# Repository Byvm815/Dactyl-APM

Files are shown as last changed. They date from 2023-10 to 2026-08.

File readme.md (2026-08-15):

## Note：I am not good at english, so writted in chinese

## 注：淘宝店铺：无名科技Nologo，有[RP2040_pico_Mini](https://item.taobao.com/item.htm?id=722773242430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)的开发板，板子宽度和ProMicro一致，无需修改外壳接口宽度,完美替换32U4。但本项目的支架适配更广，可使用常见的STM32F103、RP2040的开发板
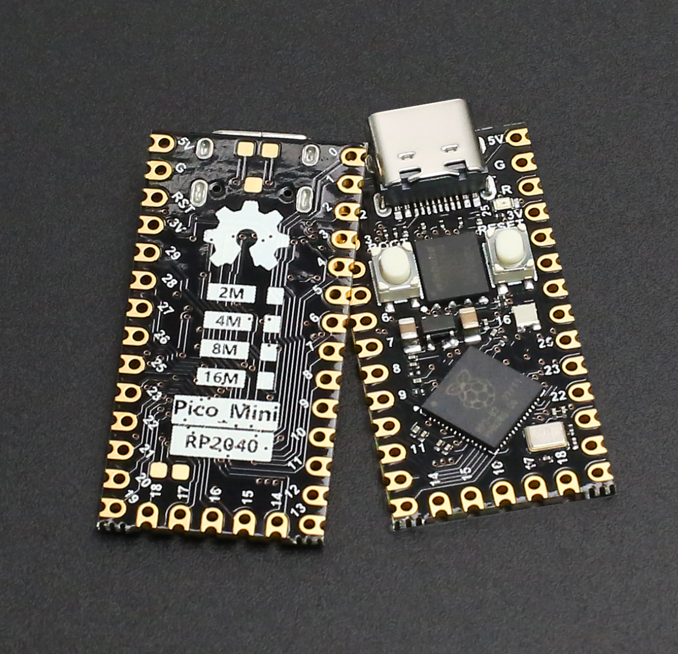
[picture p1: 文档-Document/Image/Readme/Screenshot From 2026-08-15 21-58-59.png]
Pico_Mini RP2040（16M）


## 注：本项目外壳接口宽度拓宽，与原支架不适配
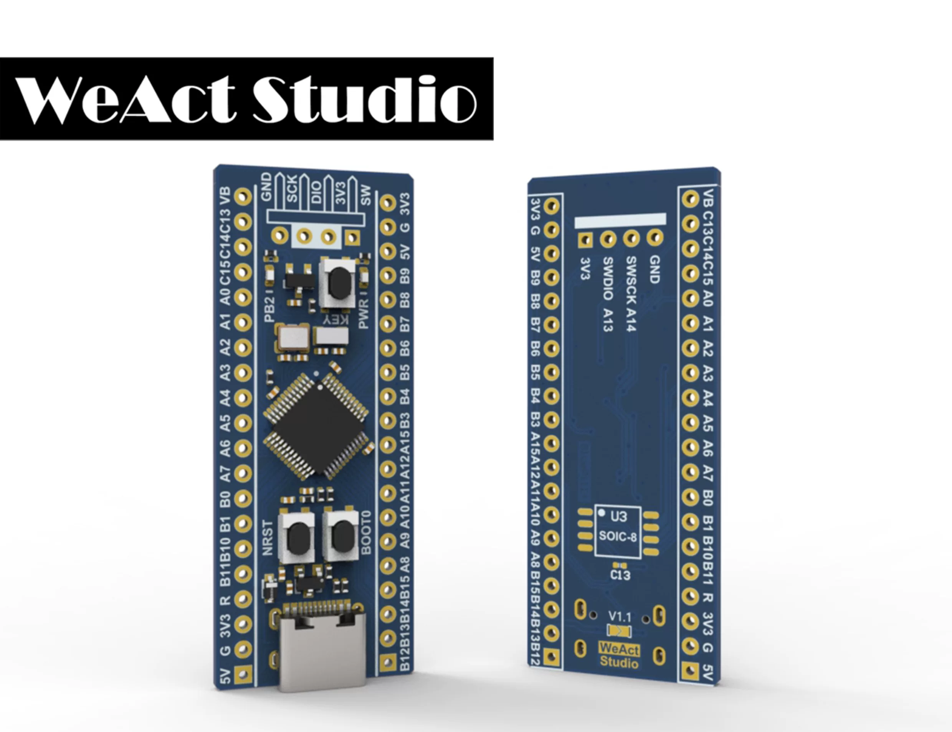
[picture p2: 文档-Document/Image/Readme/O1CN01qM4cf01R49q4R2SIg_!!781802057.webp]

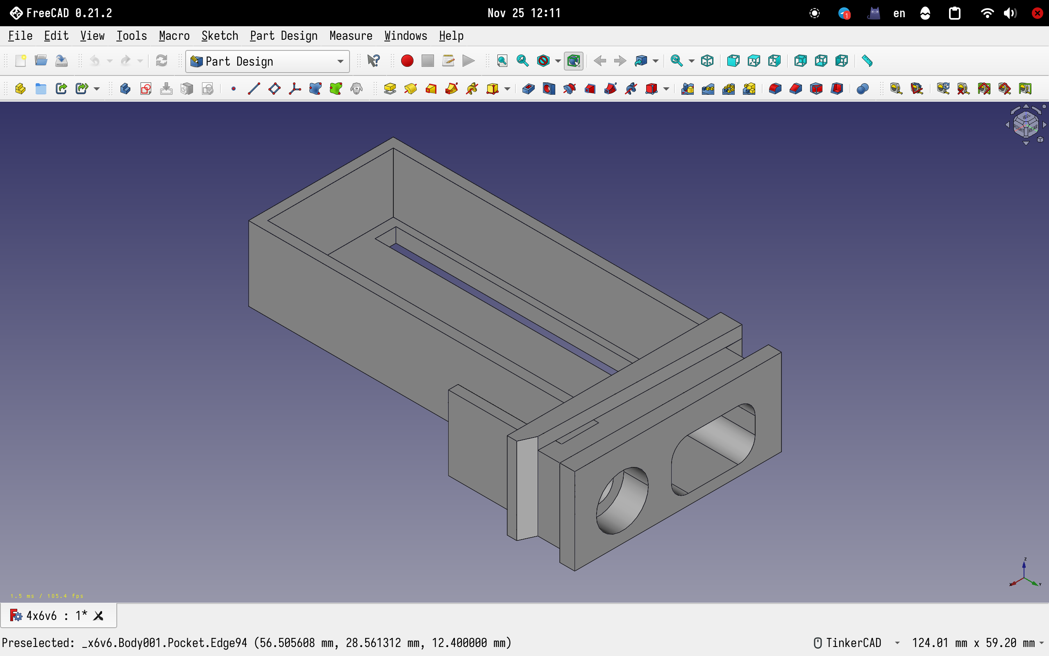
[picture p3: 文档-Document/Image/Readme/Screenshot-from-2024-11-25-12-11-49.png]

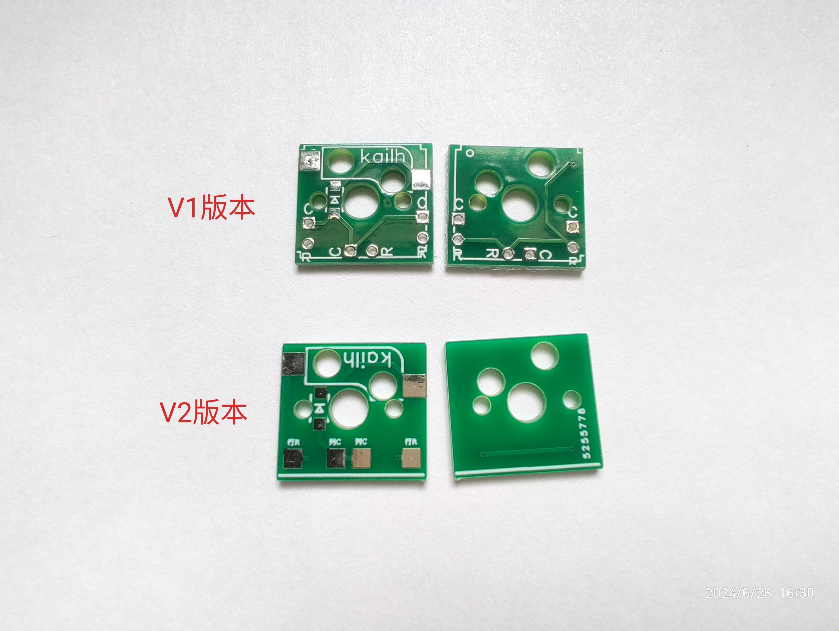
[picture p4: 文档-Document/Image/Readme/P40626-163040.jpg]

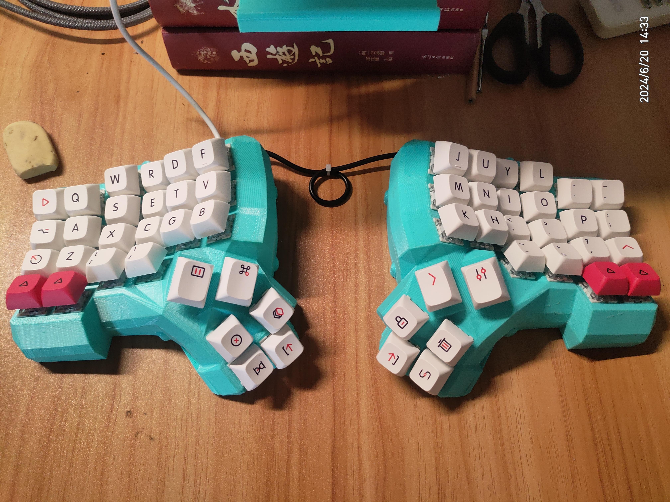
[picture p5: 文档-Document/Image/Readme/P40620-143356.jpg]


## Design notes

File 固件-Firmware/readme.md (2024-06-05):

This project test in vial-qmk version: ee7f5acefb3fa3e69b1dd2ef325ede1698bef1c9

***STM32F103xB_uf2boot.ld*** file copy from https://github.com/qmk/qmk_firmware/tree/master/platforms/chibios/boards/common/ld

Copy ***4x6v6/固件-Firmware/dactyl_apm*** to ***vial-qmk/keyboards***

Build in qmk:
```
qmk setup -H ~/Git/vial-qmk

qmk flash -kb dactyl_apm/4x6v6 -km vial -bl uf2-split-right

qmk flash -kb dactyl_apm/4x6v6 -km vial -bl uf2-split-left
```

Or build in make(pkgs:gnumake,python3,gcc-arm-embedded-8):
```
make dactyl_apm/4x6v6:vial:uf2-split-right

make dactyl_apm/4x6v6:vial:uf2-split-left
```

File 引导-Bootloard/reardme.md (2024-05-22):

Use openOCD to flash ***4x6v6/引导-Bootloard/uf2boot.bin*** , basic addr is 0x08000000

I'm using DAP-Link.

The way of link:

*DAP-Link*  ->  *APM32 Board*
TCK/CK      ->  SCK

GND         ->  GND

TMD/IO      ->  DIO

3V3         ->  3V3

Flash command
'''
sudo openocd -f interface/cmsis-dap.cfg -f target/stm32f1x.cfg -c "init;halt;reset halt;flash write_image erase uf2boot.bin 0x08000000;shutdown;"
'''

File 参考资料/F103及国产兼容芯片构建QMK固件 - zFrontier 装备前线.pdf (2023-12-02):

# F103及国产兼容芯⽚构建QMK固件

## 机械键盘

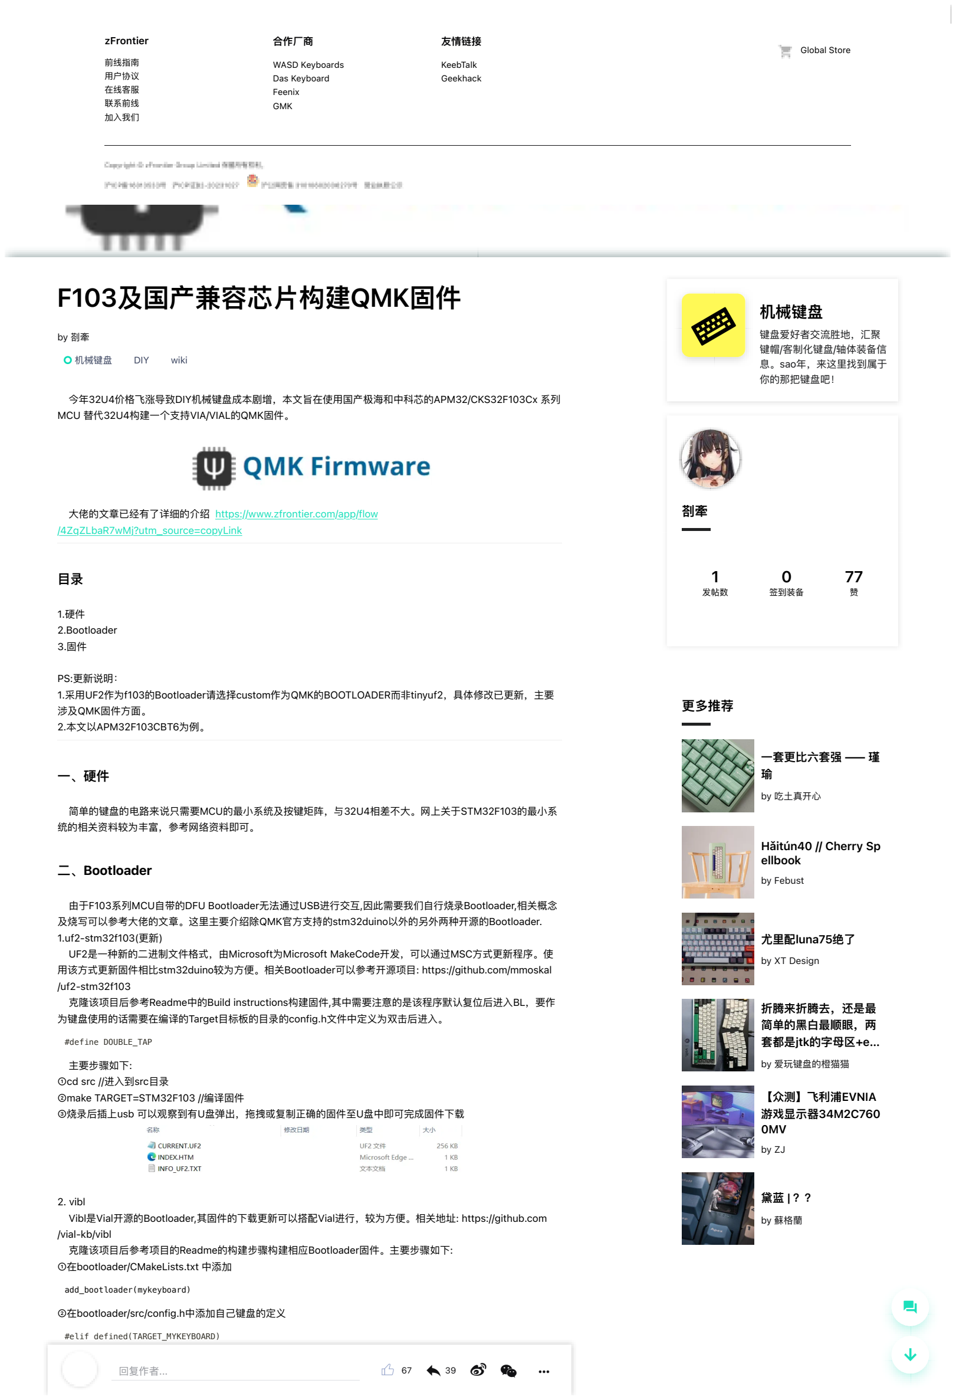
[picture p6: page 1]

by 剳牽

今年32U4价格⻜涨导致DIY机械键盘成本剧增，本⽂旨在使⽤国产极海和中科芯的APM32/CKS32F103Cx 系列 MCU 替代32U4构建⼀个⽀持VIA/VIAL的QMK固件。

⼤佬的⽂章已经有了详细的介绍 https://www.zfrontier.com/app/flow/4ZqZLbaR7wMj?utm_source=copyLink (https://www.zfrontier.com/app/flow/4ZqZLbaR7wMj?utm_source=copyLink)

⽬录

1.硬件
2.Bootloader
3.固件

PS:更新说明：
1.采⽤UF2作为f103的Bootloader请选择custom作为QMK的BOOTLOADER⽽⾮tinyuf2，具体修改已更新，主要 涉及QMK固件⽅⾯。
2.本⽂以APM32F103CBT6为例。

⼀、硬件

简单的键盘的电路来说只需要MCU的最⼩系统及按键矩阵，与32U4相差不⼤。⽹上关于STM32F103的最⼩系 统的相关资料较为丰富，参考⽹络资料即可。

## ⼆、Bootloader

由于F103系列MCU⾃带的DFU Bootloader⽆法通过USB进⾏交互,因此需要我们⾃⾏烧录Bootloader,相关概念 及烧写可以参考⼤佬的⽂章。这⾥主要介绍除QMK官⽅⽀持的stm32duino以外的另外两种开源的Bootloader. 1.uf2-stm32f103(更新)
UF2是⼀种新的⼆进制⽂件格式，由Microsoft为Microsoft MakeCode开发，可以通过MSC⽅式更新程序。使 ⽤该⽅式更新固件相⽐stm32duino较为⽅便。相关Bootloader可以参考开源项⽬: https://github.com/mmoskal/uf2-stm32f103
克隆该项⽬后参考Readme中的Build instructions构建固件,其中需要注意的是该程序默认复位后进⼊BL，要作 为键盘使⽤的话需要在编译的Target⽬标板的⽬录的config.h⽂件中定义为双击后进⼊。

#define DOUBLE_TAP

主要步骤如下:
①cd src //进⼊到src⽬录
②make TARGET=STM32F103 //编译固件
③烧录后插上usb 可以观察到有U盘弹出，拖拽或复制正确的固件⾄U盘中即可完成固件下载
2. vibl
Vibl是Vial开源的Bootloader,其固件的下载更新可以搭配Vial进⾏，较为⽅便。相关地址: https://github.com/vial-kb/vibl
克隆该项⽬后参考项⽬的Readme的构建步骤构建相应Bootloader固件。主要步骤如下: ①在bootloader/CMakeLists.txt 中添加

add_bootloader(mykeyboard)

②在bootloader/src/config.h中添加⾃⼰键盘的定义

#elif defined(TARGET_MYKEYBOARD)

// 定义键盘固件的UID,与VIAL固件相同。

#define VIAL_KEYBOARD_UID {0xXX, 0xXX, 0xXX, 0xXX, 0xXX, 0xXX, 0xXX, 0xXX}

// 定义⼀个按键⽤于进⼊Bootloader,Output/Input Bank/Pin即为该按键的输出/输⼊引脚的端⼝/引脚,根据硬件实际情况配置

键盘爱好者交流胜地，汇聚
键帽/客制化键盘/轴体装备信
息。sao年，来这⾥找到属于
你的那把键盘吧！ (https://www.zfrontier.com/app/circle/1)

1

发帖数

0

签到装备

77

赞

!机械键盘 (https://www.zfrontier.com/app/circle/1) | DIY (https://www.zfrontier.com/app/tag/97) | wiki (https://www.zfrontier.com/app/tag/2004)

剳牽

## 更多推荐

⼀套更⽐六套强⸺瑾
瑜

by 吃⼟真开⼼ (https://www.zfrontier.com/app/flow/jQVmQxrj06GZ)

Hǎitún40 // Cherry Sp
ellbook

by Febust (https://www.zfrontier.com/app/flow/0aRK0gn9gn53)

尤⾥配luna75绝了

by XT Design (https://www.zfrontier.com/app/flow/15Rn9RAy6zxP)

折腾来折腾去，还是最
简单的⿊⽩最顺眼，两
套都是jtk的字⺟区+e…

by 爱玩键盘的橙猫猫 (https://www.zfrontier.com/app/flow/EdEon7y3BEo5)

【众测】⻜利浦EVNIA
游戏显示器34M2C760
0MV

by ZJ (https://www.zfrontier.com/app/flow/7ddrPrJxMzkE)

黛蓝 | ？？

by 蘇格蘭 (https://www.zfrontier.com/app/flow/06GM7n5QqXQG)

" | # 搜索 | 登录/注册
回复作者... | 67 | $ 39 | % (http://service.weibo.com/share/share.php?appkey=4153653427) & | '

zFrontier

前线指南 (https://www.zfrontier.com/userGuide)
⽤户协议 (https://o1.zfrontier.com/license)
在线客服
联系前线 (https://www.zfrontier.com/contact)
加⼊我们 (http://www.lagou.com/gongsi/134632.html)

合作⼚商

WASD Keyboards (http://www.wasdkeyboards.com/)
Das Keyboard (http://www.daskeyboard.com/)
Feenix (http://www.feenixcollection.com/)
GMK (http://www.gmk-electronic-design.de/en.html)

友情链接

KeebTalk (https://www.keebtalk.com/)
Geekhack (https://geekhack.org/index.php?board=201.0)

Global Store (https://en.zfrontier.com/)

(

#define BL_OUTPUT_BANK GPIOB

#define BL_OUTPUT_PIN 12 (https://www.zfrontier.com/)

#define BL_INPUT_BANK GPIOB

#define BL_INPUT_PIN 13

③编译并烧录Bootloader固件
④打开Vial可以观察到有Vial Bootloader设备连接

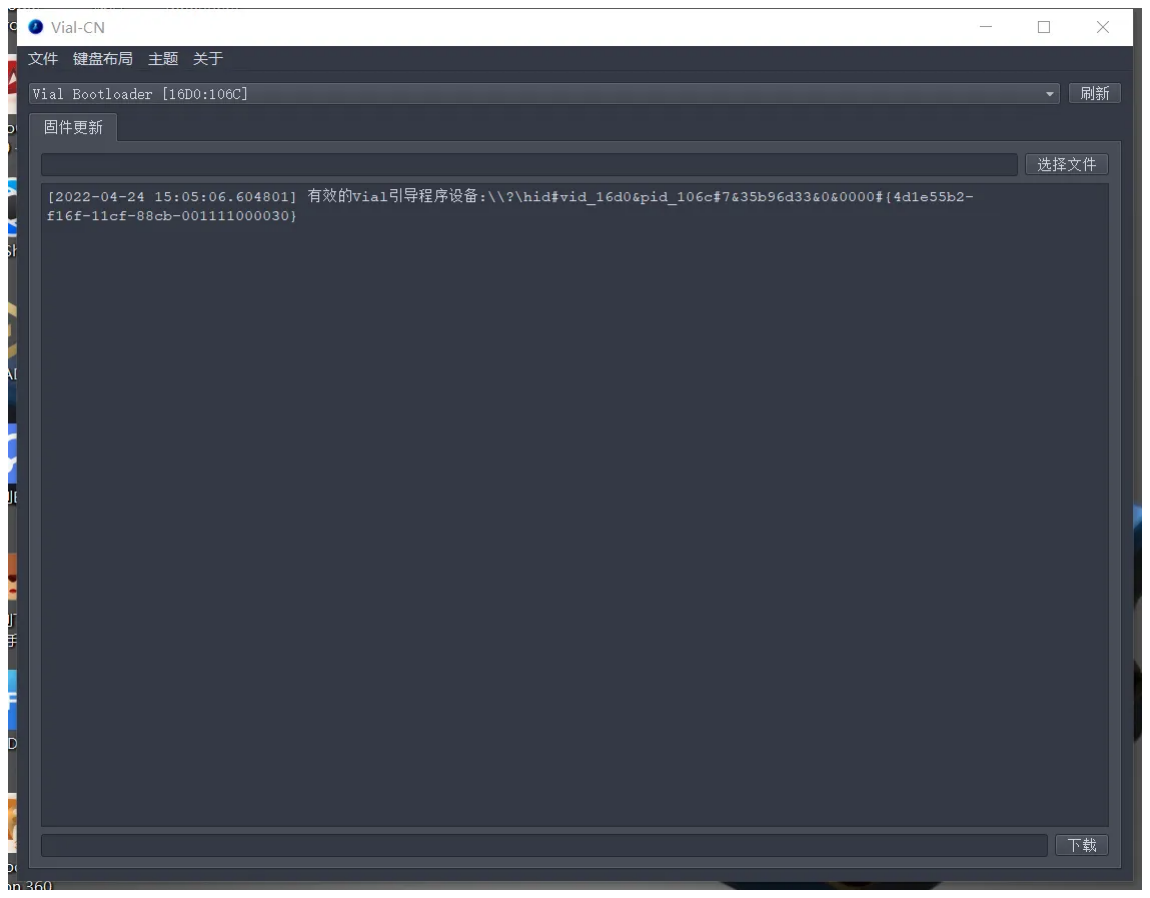
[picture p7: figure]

⑤选择正确的固件⽂件后点击下载即可

## 三、固件

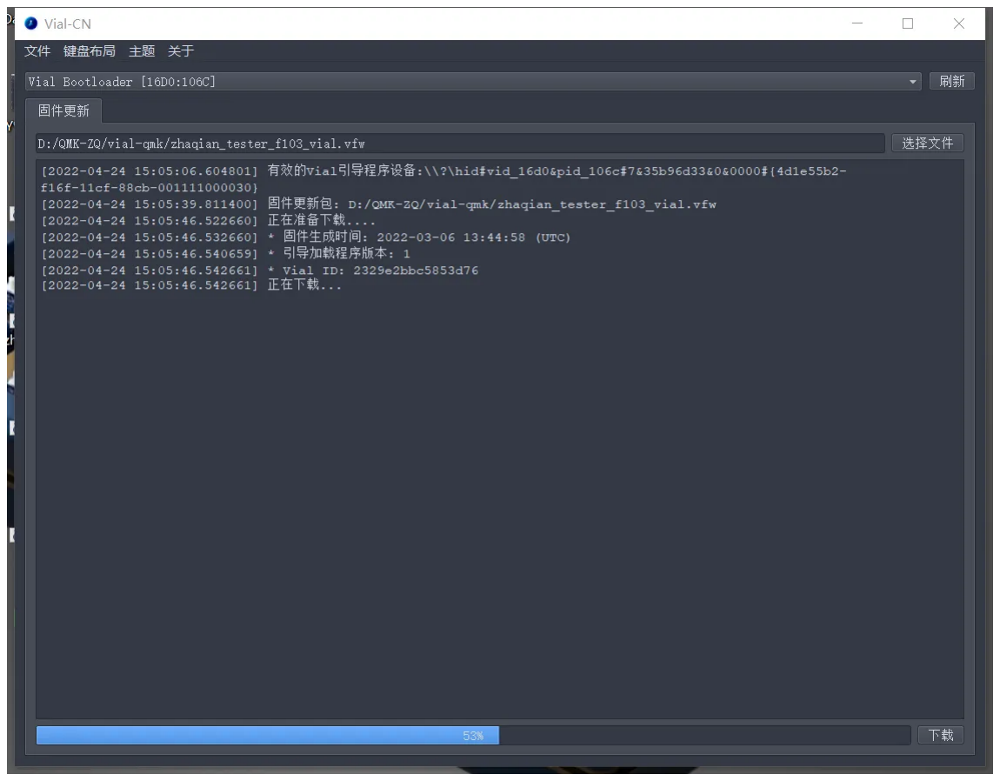
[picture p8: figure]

详细的构建固件的细节参⻅qmk⽂档ARM部分以及qmk主分⽀的相关键盘源码。 https://github.com/vial-kb/vibl 这⾥只简单的介绍⼀下构建固件与32U4的区别(前提是能够⾃⾏编译固件,参考关于qmk环境搭建的⽂章)。以 GH60配列并启⽤RGB矩阵(使⽤WS2812，以pwm驱动)为例: ①添加chconf.h⽂件配置chibios系统时钟(F103系列TIM只有16位）

#pragma once

#define CH_CFG_ST_TIMEDELTA 0

#include_next <chconf.h>

②添加halconf.h⽂件启⽤TIM及PWM:

#pragma once

#define HAL_USE_PWM TRUE

#include_next <halconf.h>

③添加mcuconf.h⽂件启⽤相应PWM(本⽂以A10引脚即TIM1为例)

#pragma once

#define STM32_PWM_USE_TIM1 TRUE

#include_next <mcuconf.h>

④在config.h中定义ws2812的PWM及DMA通道(详⻅MCU参考⼿册)

#define WS2812_PWM_DRIVER PWMD1

#define WS2812_PWM_CHANNEL 3

#define WS2812_PWM_PAL_MODE 2

#define WS2812_DMA_STREAM STM32_DMA1_STREAM5

#define WS2812_DMA_CHANNEL 5

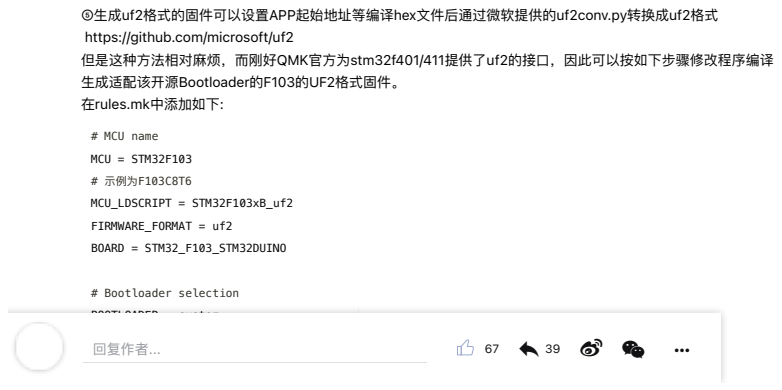
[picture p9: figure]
⑤⽣成uf2格式的固件可以设置APP起始地址等编译hex⽂件后通过微软提供的uf2conv.py转换成uf2格式 https://github.com/microsoft/uf2 但是这种⽅法相对麻烦，⽽刚好QMK官⽅为stm32f401/411提供了uf2的接⼝，因此可以按如下步骤修改程序编译 ⽣成适配该开源Bootloader的F103的UF2格式固件。 在rules.mk中添加如下:; # MCU name; MCU = STM32F103; # 示例为F103C8T6; MCU_LDSCRIPT = STM32F103xB_uf2; FIRMWARE_FORMAT = uf2; BOARD = STM32_F103_STM32DUINO; # Bootloader selection; BOOTLOADER = custom; OPT_DEFS += -DCORTEX_ENABLE_WFI_IDLE=TRUE

(

⑥参考stm32f401的ld⽂件在platforms\chibios\boards\STM32_F103_STM32DUINO\ld中添加 STM32F103xB_uf2.ld⽂件。 (https://www.zfrontier.com/)
详⻅ https://github.com/zhaqian12/qmk_firmware/blob/qmk-zq/platforms/chibios/boards/STM32_F103_STM32DUINO/ld/STM32F103xB_uf2.ld⑦在kb.c源⽂件中添加如下代码，便于QMK的QK_BOOTLOADER(RESET)键值复位键盘并跳转⾄Bootloader。(!!! 注意!!!该代码仅针对该开源项⽬的Bootloader程序.)

#define MAGIC_BOOT 0x544F4F42UL

#define MAGIC_REG *(volatile uint32_t*)0x20004000

void bootloader_jump(void) {

MAGIC_REG = MAGIC_BOOT;

NVIC_SystemReset();

}

⑧启⽤VIA 和 RGB MATRIX,由于我是通过Keyboard Firmware Builder (kbfirmware.com)⽹站⽣成的源码模板,因 此保存该⽹站的配置⽂件(SETTINGS->Save Configuration)，使⽤⼯具⽣成该键盘的VIA json配置⽂件。

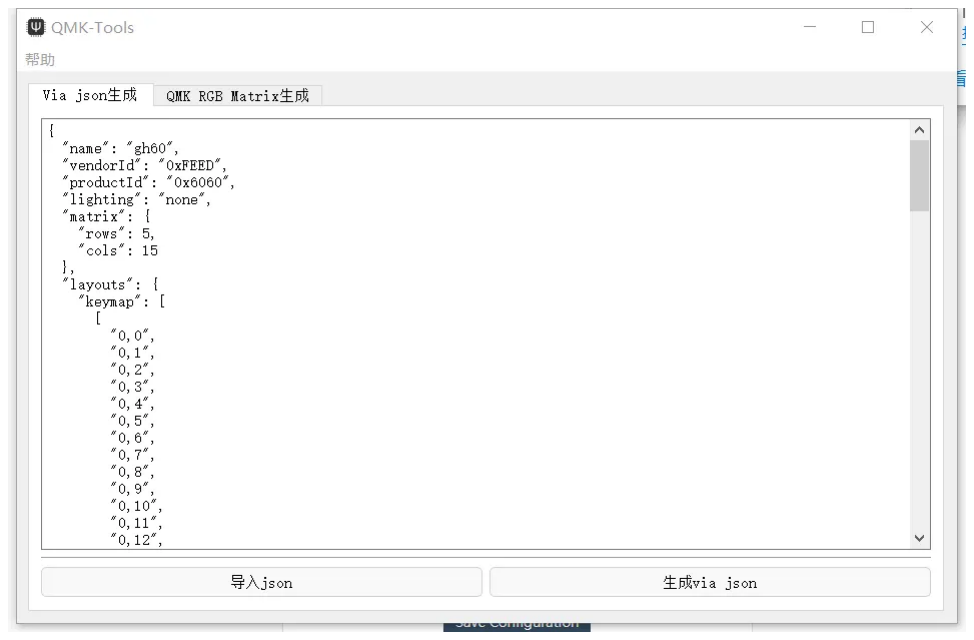
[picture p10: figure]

复制其中的keymap部分，⽣成初始的RGB矩阵并粘贴到gh60.c⽂件中。

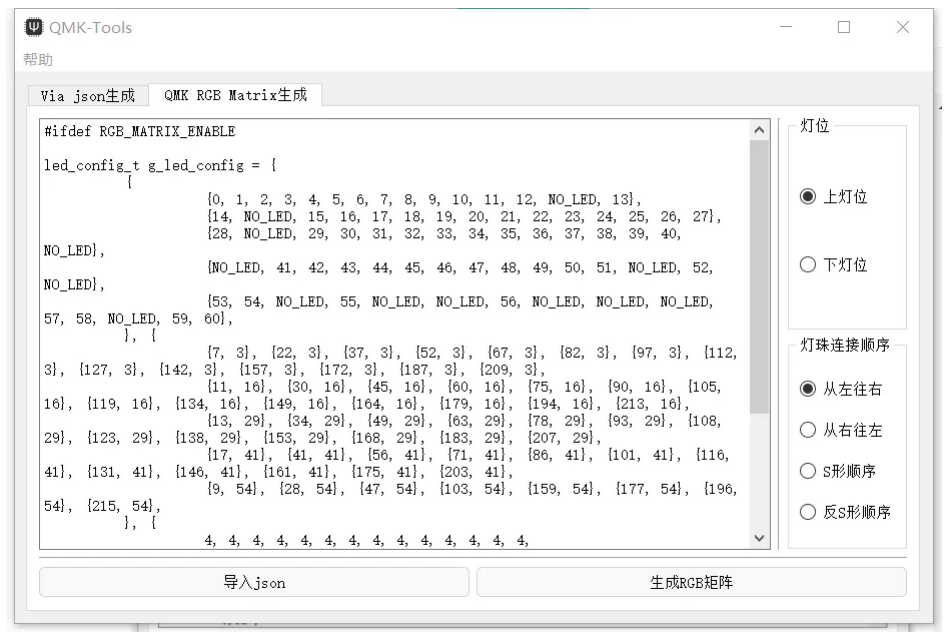
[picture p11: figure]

⼯具下载地址: https://github.com/zhaqian12/ZQ-Keyboard/blob/main/software/qmk%20tools/QMK-Tools-Windows.zip
⑨与32U4相同编译，编译固件后可以观察到有.uf2后缀的固件⽣成,拖拽或复制到U盘中即可完成固件的更新和下 载。相关示例源码⻅ https://github.com/zhaqian12/qmk_firmware/tree/qmk-zq/keyboards/zhaqian/gh60

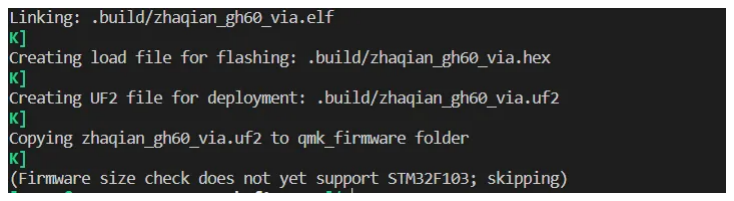
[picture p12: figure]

⑩以vibl为Bootloader的固件构建同上(除第5，6，7步)，参⻅vial官⽅构建指南（ https://get.vial.today/docs/porting-to-vial.html )，注意的是固件的键盘UID与Bootloader的UID需要⼀致，在rules.mk中将 BOOTLOADER改为vibl，并且在vial.json中添加:

"vial": {

"vibl": true

}

本⽂到这⾥就⼤概讲完了如何使⽤STM32/APM32/CKS32F103等f103系列芯⽚构建QMK固件，其中⼜不详细的地 ⽅欢迎各位⼤佬补充。如果⽂章中有错误的地⽅也欢迎各位⼤佬指正。
相关开源项⽬如下:
- [QMK Firmware]( https://github.com/qmk/qmk_firmware )
- [uf2-stm32f103]( https://github.com/mmoskal/uf2-stm32f103 )
- [vial-qmk]( https://github.com/vial-kb/vial-qmk )
- [vial-gui]( https://github.com/vial-kb/vial-gui )
- [vibl]( https://github.com/vial-kb/vibl )
- https://oshwhub.com/ythfjjh/zq50

2022.4.24 从 PC⽹⻚端 发布

$ 39 | * 收藏

67 个赞

赞 | + | % (http://service.weibo.com/share/share.php?appkey=4153653427) & | '

(

(

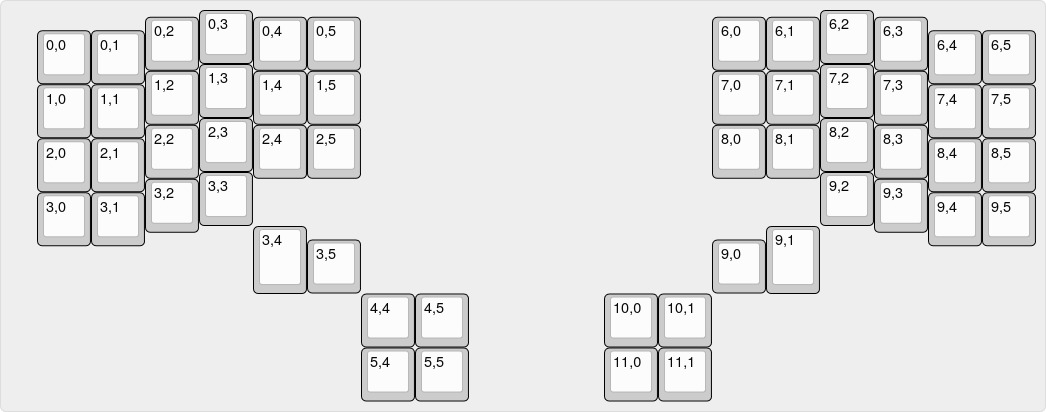
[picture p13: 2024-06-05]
固件-Firmware/dactyl_apm/4x6v6/keyboard-layout.jpg

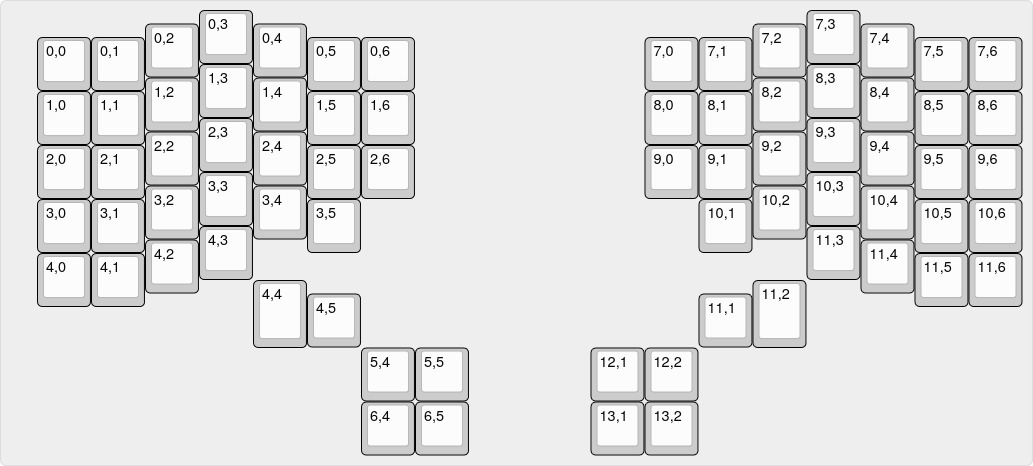
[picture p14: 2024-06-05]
固件-Firmware/dactyl_apm/5x6v6a3/keyboard-layout.jpg

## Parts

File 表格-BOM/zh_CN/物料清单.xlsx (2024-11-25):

名称 | ¥采购物价 | 单次采购所得的数量 | ¥单个物价 | 制作一对键盘所需的数量 | ¥运费 | 制作一对键盘所需的物价 | 备注 | 链接
耳机线/ 三段式 | 14.9 | 1 | 14.9 | 1 |  | 14.9 | 硬质线有弹力，不能随意拉伸，不好用 建议自己买材料焊，市面上买的都不太好用
Type-C数据线 | 4 | 1 | 4 | 1 |  | 4
XDA键帽 | 54.4 | 1 | 54.4 | 1 |  | 54.4 | 别买ABS材质的，推荐PBT材质 链接里的键帽是我用的款式 | https://item.taobao.com/item.htm?id=678080577329&_u=q3u8db4m26d4&skuId=4865165404358
外壳 | 30 | 1 | 30 | 2 |  | 60 | FDM打印，0.2元每克 FDM打印推荐PETG材质 推荐透明原色 三维猴光固化，LEDO 6060，一套要144.6*2元。9000R（性能较差），一套要91.81*2元 | https://detail.tmall.com/item.htm?_u=a3u8db4m2de9&id=649513649795&skuId=4684077365853
底板 | 11 | 1 | 11 | 2 |  | 22
主板支架 | 2 | 1 | 2 | 2 |  | 4
APM32主控 | 14.9 | 1 | 14.9 | 2 | 4 | 33.8 | 沉金、无铅板 | https://item.taobao.com/item.htm?spm=a1z09.2.0.0.145e2e8dAt2QLh&id=676894575483&_u=93u8db4m45b2
轴体 | 36 | 90 | 0.4 | 72 |  | 28.8 | 记得备注要防尘的 要性价比买灰木轴 要好听买BOX白轴 要便宜买高特轴，性能差点。但75元可以买3套，坏了就换 | https://item.taobao.com/item.htm?id=616113892809&_u=a3u8db4m6541&skuId=5320545317632
PCB轴板 | 24 | 90 | 0.2666666667 | 72 | 12 | 31.2 | 闲鱼或自己打样
二极管1N4148 /SOD-123 | 3 | 1 | 3 | 1 | 0 | 3
镀锡铜线/0.4毫米/20米 | 5 | 1 | 5 | 0.1 | 4 | 4.5 |  | https://item.taobao.com/item.htm?spm=a1z09.2.0.0.71e62e8dIKFyzM&id=638790439962&_u=a3u8db4m11f5
热插拔轴座 | 31 | 80 | 0.3875 | 72 | 4 | 31.9 | 4x6v6需要56个 5x6v6a3需要72个 | https://detail.tmall.com/item.htm?_u=93u8db4m98b1&id=640799882084&skuId=4771754166143
杜邦线/母对母/15厘米/尾部镀锡 | 5 | 100 | 0.05 | 24 |  | 1.2 | 可以买成品线，但是需要剥线镀锡，操作繁琐 | https://item.taobao.com/item.htm?id=665054009955&skuId=4790810692385
单排7P杜邦头 | 1.2 | 20 | 0.06 | 4 |  | 0.24 |  | https://item.taobao.com/item.htm?spm=a1z0d.6639537/tb.1997196601.3.3c287484hcp1og&id=522555619895
单排1P杜邦头 | 1.2 | 100 | 0.012 | 6 |  | 0.072 |  | https://item.taobao.com/item.htm?spm=a1z0d.6639537/tb.1997196601.3.3c287484hcp1og&id=522555619895
PJ-320A耳机口/直插/镀金 | 2.75 | 10 | 0.275 | 2 |  | 0.55 | 镀金的更好焊接 兼容3、4段耳机线 | https://detail.tmall.com/item.htm?id=756599475077&_u=q3u8db4m4152&skuId=5388723195957
1N4148二极管/SOD123 | 3 | 100 | 0.03 | 72 |  | 2.16 | 无铅锡 | https://item.taobao.com/item.htm?spm=a1z09.2.0.0.77f72e8deejjHh&id=38623637122&_u=93u8db4mf70e
热熔黄铜螺母/m3*3*5 | 6.2 | 50 | 0.124 | 10 |  | 1.24 |  | https://detail.tmall.com/item.htm?_u=f3u8db4m2a45&id=673367228604&skuId=5020114070504
固定螺丝/m3*6 | 5.8 | 100 | 0.058 | 10 |  | 0.58 |  | https://detail.tmall.com/item.htm?_u=f3u8db4m1773&id=643512747051&skuId=4623803564419
无铅焊锡 | 60 | 200 | 0.3 | 17 |  | 5.1 | 一对要十几克
助焊剂 | 6 | 60 | 0.1 | 2 |  | 0.2
热熔胶 | 16 | 80 | 0.2 | 1 |  | 0.2
¥采购物料总价 | 423.25 |  |  |  | ¥制作一对键盘所需的物料总价 | 328.042 | CC-BY-SA 4.0

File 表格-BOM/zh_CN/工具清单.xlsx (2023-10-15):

名称 | ¥采购物价 | ¥运费 | 备注 | 链接
一个舒适的焊接环境 |  |  | 要有台灯
T12电烙铁 | 130
清洁铜球 | 8.2 | 2
烙铁支架 | 6.6
镊子 | 2.5
手套 | 4 |  | 小心烙铁烫手
透明面罩 | 5 |  | 松香芯的焊锡丝，焊接时松香会飞溅，入眼就麻烦了
热熔胶枪 | 10
电子斜口钳 | 3.4
内六角螺丝刀 | 6
DAP-Link | 28 | 3
 | 203.7
 |  |  | CC-BY-SA 4.0

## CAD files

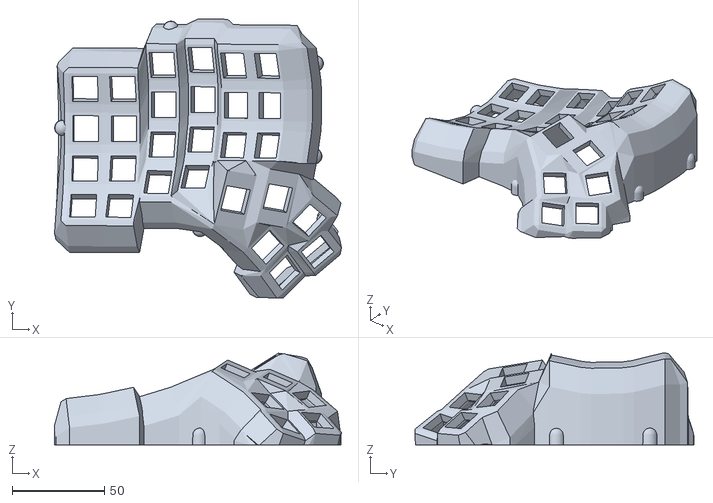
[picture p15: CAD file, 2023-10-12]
模型-Model/4x6v6/外壳-Case/manuform-case-left-Full_Key.stl
155.9 x 151.5 x 49.9

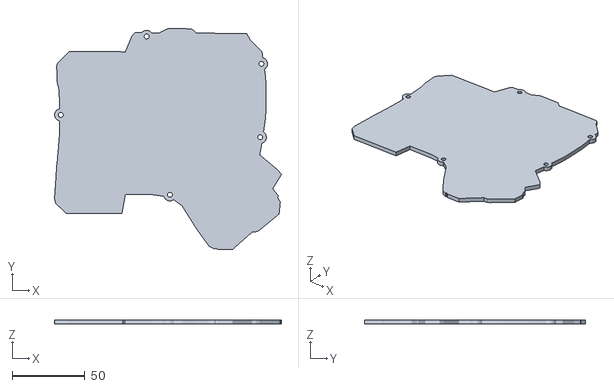
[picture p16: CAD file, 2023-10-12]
模型-Model/4x6v6/底板-Plate/manuform-plate-left.stl
155.6 x 151.4 x 3.00

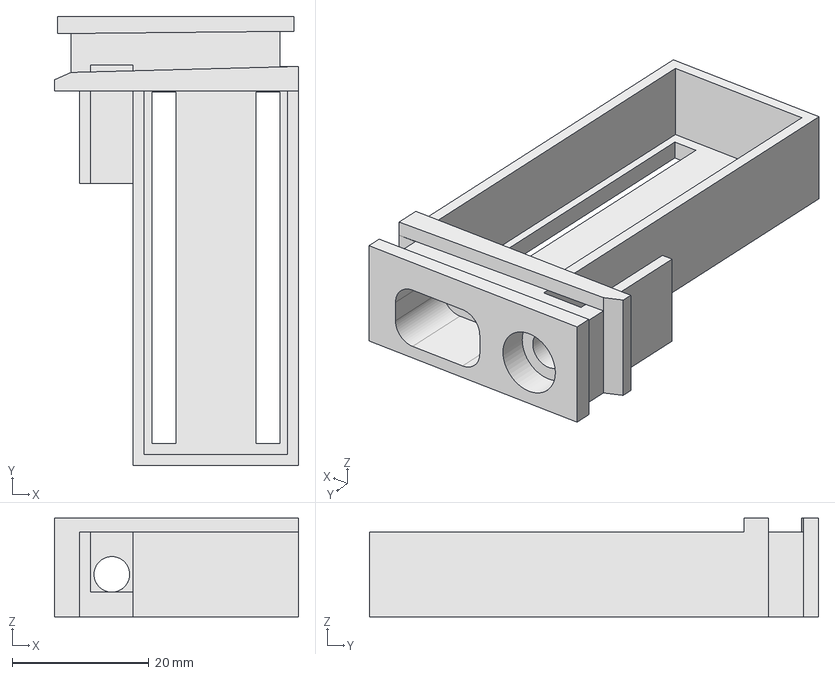
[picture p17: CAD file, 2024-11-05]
模型-Model/4x6v6/支架-Holder/4x6v6-左001 (Mirror #1).step
35.7 x 65.6 x 14.4 mm

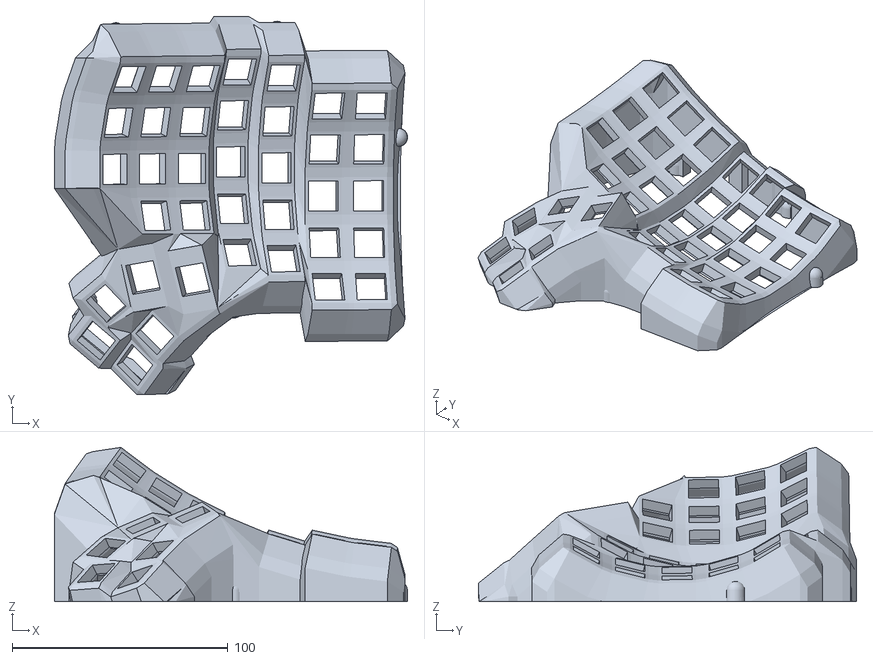
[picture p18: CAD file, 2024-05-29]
模型-Model/5x6v6a3/外壳-Case/manuform-case-right-2024.05.29-08.08.25.stl
163.6 x 175.0 x 71.4

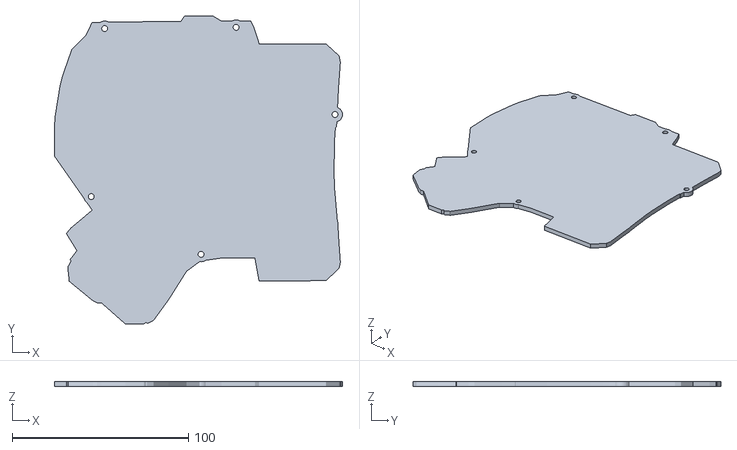
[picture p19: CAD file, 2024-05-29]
模型-Model/5x6v6a3/底板-Plate/manuform-plate-2024.05.29-08.08.28.stl
163.6 x 174.9 x 3.00

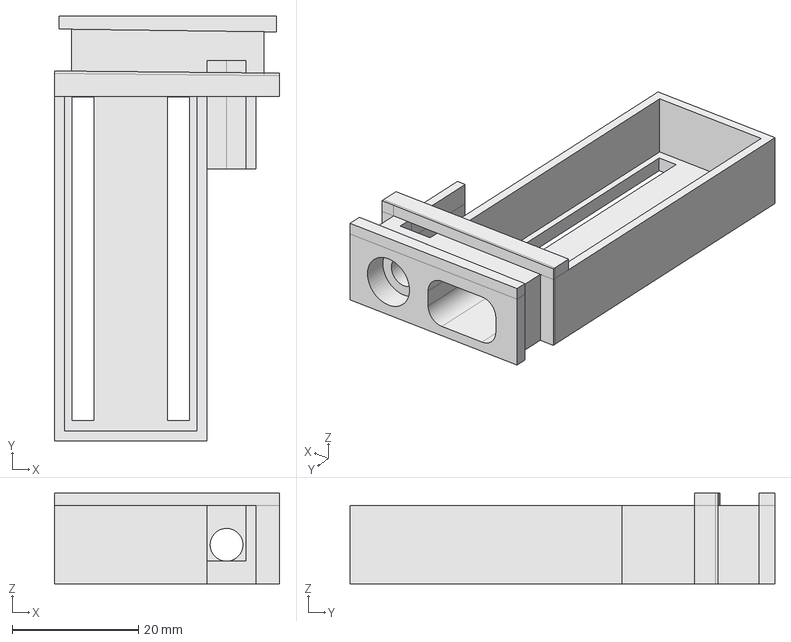
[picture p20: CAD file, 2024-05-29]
模型-Model/5x6v6a3/支架-Holder/5x6v6a3-左.step
35.7 x 67.4 x 14.4 mm

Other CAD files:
模型-Model/4x6v6/外壳-Case/manuform-case-right-Full_Key.stl
模型-Model/4x6v6/底板-Plate/manuform-plate-right.stl
模型-Model/4x6v6/支架-Holder/4x6v6-左.step
模型-Model/4x6v6/外壳-Case/manuform-case-left-Full_Key.scad
模型-Model/4x6v6/外壳-Case/manuform-case-right-Full_Key.scad
模型-Model/5x6v6a3/外壳-Case/manuform-case-right-2024.05.29-08.08.25.scad
模型-Model/5x6v6a3/底板-Plate/manuform-plate-2024.05.29-08.08.28.scad
模型-Model/4x6v6/底板-Plate/manuform-plate-left.scad
模型-Model/4x6v6/底板-Plate/manuform-plate-right.scad

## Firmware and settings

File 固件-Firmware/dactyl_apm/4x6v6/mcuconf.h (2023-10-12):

/* Copyright 2020 QMK
 *
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
 * You should have received a copy of the GNU General Public License
 * along with this program.  If not, see <http://www.gnu.org/licenses/>.
 */

/*
 * This file was auto-generated by:
 *    `qmk chibios-confmigrate -i keyboards/rocketboard_16/mcuconf.h -r platforms/chibios/STM32_F103_STM32DUINO/configs/mcuconf.h`
 */

#pragma once

#include_next <mcuconf.h>

#undef STM32_SERIAL_USE_USART1
#define STM32_SERIAL_USE_USART1 TRUE

/*
#undef STM32_LSI_ENABLED
#define STM32_LSI_ENABLED TRUE

#undef STM32_LSE_ENABLED
#define STM32_LSE_ENABLED TRUE

#undef STM32_I2C_USE_I2C1
#define STM32_I2C_USE_I2C1 TRUE

#undef STM32_PWM_USE_TIM2
#define STM32_PWM_USE_TIM2 TRUE

#undef STM32_SPI_USE_SPI1
#define STM32_SPI_USE_SPI1 TRUE

#undef STM32_SPI_USE_SPI2
#define STM32_SPI_USE_SPI2 FALSE
*/

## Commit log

2023-10-12 添加.gitignore
2023-10-12 添加固件
2023-10-12 添加模型
    [APM支架-左.step, APM支架-左001 (Mirror #1).step, manuform-case-left-Full_Key.scad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]
2023-10-12 添加物料
    [工具清单.xlsx, 物料清单.xlsx]
2023-10-12 添加引导
2023-10-12 添加参考资料
2023-10-14 更改耳机线链接
    [物料清单.xlsx]
2023-10-14 添加DAP-Link
    [工具清单.xlsx]
2023-10-14 添加Github链接
2023-10-15 优化备注、更改FDM打印价格为0.2元每克
    [物料清单.xlsx]
2023-10-15 添加许可证
    [工具清单.xlsx, 物料清单.xlsx]
2023-10-20 删除文件夹名称中的英文
2023-10-20 更改轴体为BOX白轴
    [物料清单.xlsx]
2023-10-20 更改布局
2023-10-20 优化布局缩进
2023-12-02 修复错误的左右手区分方式
2023-12-02 为第二键盘布局预留层
2023-12-02 启用全键无冲
2023-12-02 添加对应左右手的UF2固件(未测试)
2023-12-02 添加引导固件说明
2024-05-17 优化支架
    [APM支架-左.step, APM支架-左001 (Mirror #1).step]
2024-05-22 添加引导烧录命令
2024-05-23 更改split_pin
2024-05-29 添加5x7v6+3的原文件
    [manuform-case-right-2024.05.29-08.08.25.scad, manuform-plate-2024.05.29-08.08.28.scad]
2024-05-29 优化模型：添加细分函数
    [manuform-case-right-2024.05.29-08.08.25.scad, manuform-plate-2024.05.29-08.08.28.scad]
2024-05-29 优化模型：孔洞适配M3*3*5的黄铜螺母
    [manuform-case-right-2024.05.29-08.08.25.scad]
2024-05-29 优化模型：支架接口加宽1.6mm,且向右移动3.2 - 1.6/2mm
    [manuform-case-right-2024.05.29-08.08.25.scad]
2024-05-29 添加：5x7v6+3的STL文件
    [manuform-case-right-2024.05.29-08.08.25.stl, manuform-plate-2024.05.29-08.08.28.stl]
2024-05-29 优化模型：支架接口调整为向右移动6.0 - 1.6/2mm
    [manuform-case-right-2024.05.29-08.08.25.scad, manuform-case-right-2024.05.29-08.08.25.stl]
2024-05-29 添加：5x7v6+3的支架
    [APM支架-左.step]
2024-06-05 添加：4x6v6矩阵图片
2024-06-05 添加：5x6v6a3的固件代码，成功编译，但未测试
2024-06-05 重命名文件名称
2024-06-05 更改readme.md
2024-06-05 添加：5x6v6a3的UF2固件
2024-06-09 优化文件结构
    [APM支架-左.step, APM支架-左001 (Mirror #1).step, manuform-case-left-Full_Key.scad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]
2024-06-10 优化制造商名称
2024-06-26 添加：轴板文件及其图片
2024-11-05 优化4x6v6支架，耳机座凹槽加深1.09mm,以使耳机口通孔间距缩短为3mm。（之前不做是因为有BUG，凹槽操作会影响实体的面数量，导致后续操作失效）
    [4x6v6-左.step, 4x6v6-左001 (Mirror #1).step]
2024-11-05 更新PCB

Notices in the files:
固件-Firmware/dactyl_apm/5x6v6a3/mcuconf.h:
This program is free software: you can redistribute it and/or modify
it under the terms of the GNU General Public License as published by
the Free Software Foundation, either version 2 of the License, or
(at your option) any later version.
